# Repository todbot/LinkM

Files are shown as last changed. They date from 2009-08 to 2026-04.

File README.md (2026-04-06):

# LinkM -- USB to I2C adapter for BlinkM Smart LEDs

2010-2026 Tod E. Kurt, ThingM

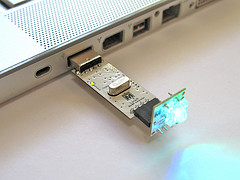
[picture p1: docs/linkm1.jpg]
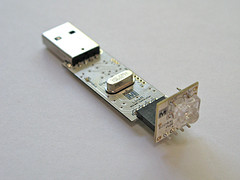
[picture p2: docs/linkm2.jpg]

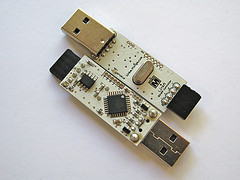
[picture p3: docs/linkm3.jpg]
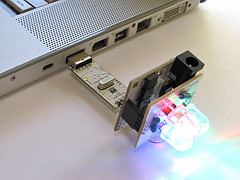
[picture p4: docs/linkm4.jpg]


LinkM datasheet: https://github.com/todbot/LinkM/raw/master/docs/LinkM_datasheet.pdf

Hosted on Github at https://github.com/todbot/LinkM/

## BlinkMSequencer

Create BlinkM light scripts using a drum machine-style metaphor and requires no
programming or hardware experience.

Modern BlinkMSequencer at https://github.com/todbot/BlinkMSequencer

Available for MacOS / Windows / Linux.

## linkm-tool

Commandline tool for controlling LinkM and BlinkMs.

Pre-compiled versions available in the [Releases section](https://github.com/todbot/LinkM/releases).

## Repo contents

This project contains the following directories:

- c_host          -- C library for talking to LinkM
  - linkm-tool       -- Command-line tool for exercising C library

- java_host       -- Java library for talking to LinkM
  - linkm.sh         -- Command-line tool for exercising Java library

- processing_apps -- Several applications using Java library and Processing
  - BlinkMSequencer2 -- Multi-channel light sequencer
  - BlinkMScriptTool -- Helps write text light scripts
  - TwitterBlinkM    -- Turns BlinkMs colors from twitter stream mentions
  - OSCLinkM         -- OSC gateway for LinkM
  - LinkMLibTest     -- Simple tests of LinkM Processing/Java library

- tools           -- Misc tools
  - linkm_load       -- mass bootloading tool
  - linux_usb_setup  -- fixes USB permissions on Ubuntu & other udev Linux

- schematic       -- LinkM device schematics in Eagle format

- firmware        -- LinkM device firmware code

- bootloadHID     -- LinkM device bootloader firmware and commandline tool
  - firmware         -- firmware for bootloader
  - commandline      -- commandline host-side tool to upload new firmware

## Building linkm-tool

The build process for linkm-tool is expected to be done entirely from the
command-line using standard free Unix-like tools such as "make" and "gcc".

On unix-like environments, the build process is just:

```sh
cd LinkM/c_host
make
```

Dependencies:
- The C library in "c_host" depends on library in "bootloadHID/commandline"
- `c_host/linkm-tool` requires **hidapi** (replaces the older libusb dependency)

On Mac OS X you will need the following free tools:
- XCode - http://developer.apple.com/technologies/xcode.html
- hidapi - `brew install hidapi`

On Windows (MinGW/MSYS2) you will need:
- MinGW/MSYS2 - https://www.msys2.org/
- The Windows build uses the native Win32 HID API; no extra library needed.

On Ubuntu / Debian Linux you will need:
- build-essential - `sudo apt-get install build-essential`
- hidapi - `sudo apt-get install libhidapi-dev`

On Fedora / RHEL Linux:
- `sudo dnf install hidapi-devel`

On Arch Linux:
- `sudo pacman -S hidapi`

On Linux, non-root users also need permission to access the device.
Add udev rules and reload:

```sh
cat << 'EOF' | sudo tee /etc/udev/rules.d/99-linkm.rules
SUBSYSTEM=="hidraw", ATTRS{idVendor}=="20a0", ATTRS{idProduct}=="4110", MODE="0666"
SUBSYSTEM=="usb",    ATTR{idVendor}=="20a0",  ATTR{idProduct}=="4110",  MODE="0666"
EOF
sudo udevadm control --reload-rules && sudo udevadm trigger
```

### Building the LinkM firmware

In general you should have everything you have for the host code above, and:

On Mac OS X:
- AVR CrossPack - http://www.obdev.at/products/crosspack/

On Windows:
- WinAVR - http://winavr.sourceforge.net/

On Ubuntu Linux:
- "sudo apt-get install avrdude avr-libc avr-gcc avr-binutils"

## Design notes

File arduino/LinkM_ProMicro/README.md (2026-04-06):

# LinkM Emulator for Arduino Pro Micro (ATmega32U4)

Make an Arduino act like a ThingM LinkM!

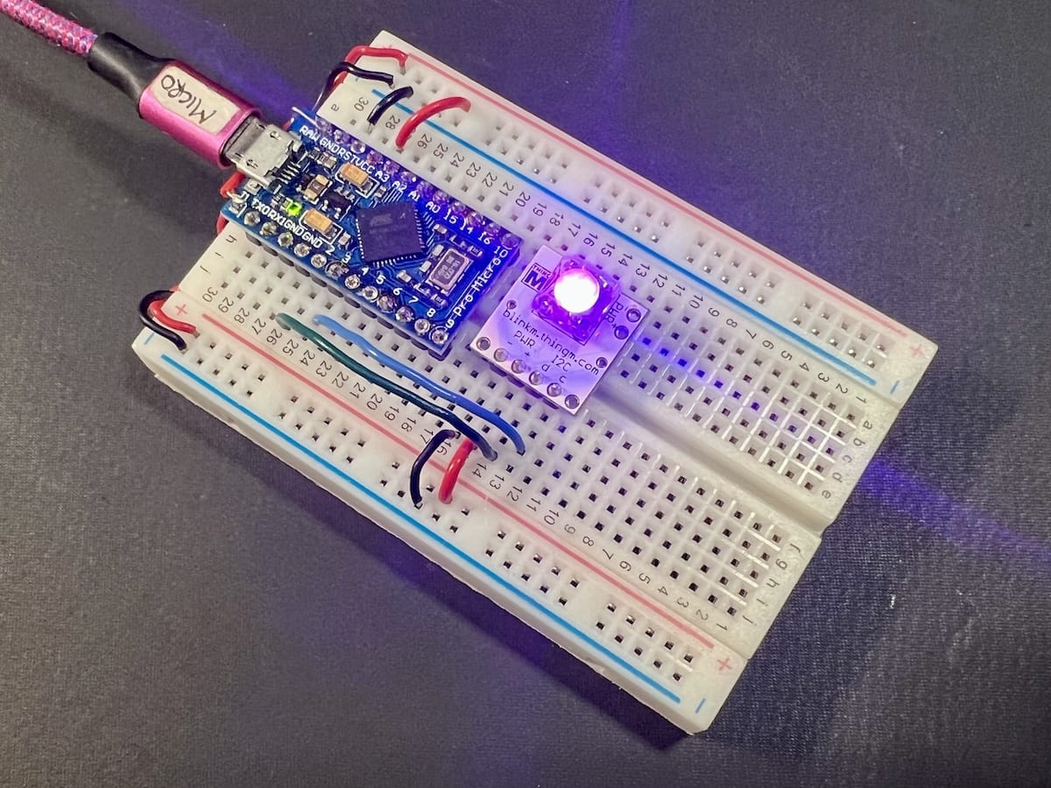
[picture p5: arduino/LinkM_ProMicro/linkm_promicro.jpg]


Firmware that turns a SparkFun Pro Micro (ATmega32U4) into a drop-in replacement
for a ThingM LinkM USB HID to I2C adapter.  The emulator implements the same USB
HID identity and feature-report protocol as the original hardware.

The host-side tool (`c_host/linkm-tool`) must be built from this repository — it
uses hidapi rather than libusb, which allows the Pro Micro's CDC serial interface
to remain active alongside the HID interface.

---

## What this does

The original LinkM is an ATmega88P device using V-USB (software USB) to present a
USB HID interface to the host.  The host sends commands via **HID feature reports**
(SET_REPORT / GET_REPORT control transfers, Report ID 1, 8 bytes) which the firmware
translates into I2C transactions.

This sketch ports that firmware to the ATmega32U4's native USB hardware, using
Arduino's `PluggableUSB` API to implement the same HID descriptor and feature-report
protocol.  From the host's perspective the device is identical:

| Property | Value |
|---|---|
| USB Vendor ID  | `0x20A0` |
| USB Product ID | `0x4110` |
| Manufacturer | `ThingM` |
| Product | `LinkM` |
| HID interface  | Vendor feature report, Report ID 1, 8 bytes |

---

## File overview

| File | Purpose |
|---|---|
| `LinkM_ProMicro.ino`  | `setup()` / `loop()` — 10 lines |
| `LinkMHID.h` | `PluggableUSBModule` subclass declaration |
| `LinkMHID.cpp` | USB descriptors, feature-report handling, all 13 commands, I2C via Wire, EEPROM, play-ticker |
| `linkm_protocol.h` | Command/error constants (mirrors `c_host/linkm-lib.h`) |

---

## Hardware

**Board:** SparkFun Pro Micro — **5V / 16 MHz** variant (ATmega32U4)

> **Important:** The SparkFun Pro Micro board package defaults to the
> **3.3 V / 8 MHz** processor option.  You must select **ATmega32U4 (5V, 16 MHz)**
> before compiling.  At 8 MHz the USB timing is out of spec for full-speed USB
> and the device will fail to enumerate reliably.
>
> In the Arduino IDE: **Tools → Processor → ATmega32U4 (5V, 16 MHz)**
>
> With arduino-cli the FQBN option `:cpu=16MHzatmega32U4` (shown in all compile
> commands below) selects this mode.

**I2C wiring:**

| Pro Micro pin | Signal | Notes |
|---|---|---|
| 2 (SDA) | SDA | 4.7 kΩ pull-up to VCC |
| 3 (SCL) | SCL | 4.7 kΩ pull-up to VCC |
| GND | GND | Common ground with I2C devices |

The I2C bus runs at 100 kHz.  Pro Micro is the bus master; all BlinkMs and other
I2C peripherals are slaves.

---

## Prerequisites

### 1. arduino-cli

```sh
brew install arduino-cli      # macOS
# or download from https://arduino.cc/en/software#arduino-cli
```

Verify:

```sh
arduino-cli version
```

### 2. SparkFun AVR board package

```sh
arduino-cli config init
arduino-cli config add board_manager.additional_urls \
    https://raw.githubusercontent.com/sparkfun/Arduino_Boards/master/IDE_Board_Manager/package_sparkfun_index.json
arduino-cli core update-index
arduino-cli core install SparkFun:avr
```

Verify the Pro Micro board is visible:

```sh
arduino-cli board listall | grep promicro
# SparkFun Pro Micro    SparkFun:avr:promicro
```

### 3. No extra libraries required

All libraries used (`Wire`, `EEPROM`, `PluggableUSB`) are part of the Arduino AVR
core and ship with `SparkFun:avr`.

---

## Compile

The Pro Micro defaults to SparkFun's VID/PID (`0x1B4F / 0x9206`).  Pass the
LinkM identity flags on the command line:

```sh
cd LinkM/arduino/LinkM_ProMicro

arduino-cli compile \
    --fqbn SparkFun:avr:promicro:cpu=16MHzatmega32U4 \
    --build-property "build.extra_flags=-DUSB_VID=0x20A0 -DUSB_PID=0x4110 -DUSB_MANUFACTURER=\"ThingM\" -DUSB_PRODUCT=\"LinkM\"" \
    --clean \
    .
```

### Alternative: platform.local.txt

To avoid repeating the flags on every compile, create a `platform.local.txt`
file that injects them automatically:

```sh
PLATFORM_DIR=$(arduino-cli config dump --format json | \
    python3 -c "import sys,json; d=json.load(sys.stdin); \
    print(d['directories']['data'])")/packages/SparkFun/hardware/avr/1.1.13

cat > "$PLATFORM_DIR/platform.local.txt" << 'EOF'
build.extra_flags=-DUSB_VID=0x20A0 -DUSB_PID=0x4110 -DUSB_MANUFACTURER="ThingM" -DUSB_PRODUCT="LinkM"
EOF
```

With that file in place the shorter form works:

```sh
arduino-cli compile \
    --fqbn SparkFun:avr:promicro:cpu=16MHzatmega32U4 \
    --clean \
    .
```

> `platform.local.txt` is loaded after `platform.txt` and survives IDE/CLI
> restarts, but must be recreated if the SparkFun package is updated to a new
> version directory.

---

## Upload

The board appears as a CDC serial port while running.  Find the port and upload:

```sh
arduino-cli board list
# Port                    Protocol  Type              Board Name
# /dev/cu.usbmodem14101   serial    Serial Port (USB) SparkFun Pro Micro

arduino-cli upload \
    --fqbn SparkFun:avr:promicro:cpu=16MHzatmega32U4 \
    --port /dev/cu.usbmodem14101 \
    .
```

If the board is unresponsive (no serial port visible), force it into the
Caterina bootloader manually:

1. **Briefly connect RST to GND twice in quick succession** (the Pro Micro has
   no reset button — use a jumper wire or tweezers on the RST and GND pins).
   The RX LED will begin pulsing, indicating the bootloader is active.
2. Within 8 seconds, find the bootloader port and upload:

```sh
arduino-cli board list
# find the new port, then:
arduino-cli upload \
    --fqbn SparkFun:avr:promicro:cpu=16MHzatmega32U4 \
    --port /dev/cu.usbmodem14101 \
    .
```

> The bootloader port is a different path from any previous port.  Run
> `arduino-cli board list` immediately after the double-tap to see it.
>
> If the upload still fails, try again — the timing window is ~8 seconds.

After a successful upload the board re-enumerates with VID=0x20A0 / PID=0x4110,
presenting both a CDC serial port and the HID interface.

---

## Verify enumeration

**macOS:**

```sh
system_profiler SPUSBDataType | grep -A 8 "LinkM"
```

Expected output:

```
LinkM:
  Product ID: 0x4110
  Vendor ID: 0x20a0
  Manufacturer: ThingM
  ...
```

**Linux:**

```sh
lsusb -d 20a0:4110
# Bus 001 Device 012: ID 20a0:4110 ThingM LinkM
```

---

## Test with linkm-tool

Build the host tool from this repository:

```sh
cd LinkM/c_host
make
```

Run tests (no I2C hardware needed for the first two):

```sh
# Firmware version — exercises a full SET_REPORT + GET_REPORT round-trip
./linkm-tool --linkmversion
# Expected: LinkM version 0x13 0x36

# Status LED toggle
./linkm-tool --statled 1
./linkm-tool --statled 0

# I2C scan (requires devices on SDA/SCL with pull-ups)
./linkm-tool --i2cscan

# BlinkM at address 9: stop, set colour to red, play script 0
./linkm-tool -a 9 --stop
./linkm-tool -a 9 --color 255,0,0
./linkm-tool -a 9 --play 0

# EEPROM round-trip
./linkm-tool --linkmeesave
./linkm-tool --linkmeeload
./linkm-tool --linkmversion   # confirm still responsive
```

---

## Implementation notes

### Commands supported

All 13 original LinkM commands are implemented:

| Cmd | Value | Notes |
|-----|---|---|
| I2CTRANS | 1 | Write + optional repeated-START read |
| I2CWRITE | 2 | Write, optionally hold bus open |
| I2CREAD | 3 | Read only |
| I2CSCAN | 4 | Probe each address; returns list of ACK'd devices |
| I2CCONN | 5 | No-op (no bus-isolation chip on Pro Micro) |
| I2CINIT | 6 | `Wire.end()` / `Wire.begin()` / `setClock(100000)` |
| VERSIONGET | 100 | Returns `0x13` / `0x36` (matches original firmware) |
| STATLEDSET | 101 | TX LED (pin 30, `LED_BUILTIN_TX`) — persistent state |
| STATLEDGET | 102 | |
| PLAYSET | 103 | Sets autonomous BlinkM play-ticker params |
| PLAYGET | 104 | |
| EESAVE | 105 | `EEPROM.put()` at address 0 |
| EELOAD | 106 | `EEPROM.get()` at address 0 |
| GOBOOTLOAD | 107 | Writes Caterina magic key `0x7777` → watchdog reset |

### PLAYSET buffer limit

The 8-byte feature report can carry at most 4 param bytes for PLAYSET (indices
4–7 of `rxBuf`): `playing`, `script_id`, `script_tick`, `script_len`.  The
original firmware had the same effective limit.  `start_pos`, `fadespeed`, and
`dir` are preserved from the last EELOAD or retain their defaults.

### Play-ticker timing

The original firmware fired at `12 MHz / 65536 / 6 ≈ 30.5 Hz` giving ~32.8 ms
per tick.  The emulator uses `millis()` with 33 ms per tick unit to match this
rate.

### I2C repeated START

`Wire.endTransmission(false)` (sendStop=false) is used when a read follows a
write in the same I2CTRANS command, issuing a repeated START rather than a
STOP+START.  This is required by BlinkM and many other I2C peripherals.

### Linux udev rule

On Linux, add udev rules so non-root users can access the device.  Two rules are
needed: one for the hidraw node (used by hidapi) and one for the USB device:

```sh
cat << 'EOF' | sudo tee /etc/udev/rules.d/99-linkm.rules
SUBSYSTEM=="hidraw", ATTRS{idVendor}=="20a0", ATTRS{idProduct}=="4110", MODE="0666"
SUBSYSTEM=="usb",    ATTR{idVendor}=="20a0",  ATTR{idProduct}=="4110",  MODE="0666"
EOF
sudo udevadm control --reload-rules && sudo udevadm trigger
```

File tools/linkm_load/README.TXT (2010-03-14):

LinkMv1 Testing Script            -- 20100314, ThingM, Tod E. Kurt
======================

Note:
-----
- This script assumes a Windows computer is the USB host.  
- A Linux computer may also be used (with optional file supplied)
- The "linkm_load.bat" batch file runs in a loop to speed testing

Script:
-------
1. Connect shorting jumper across pins 'o' and '-' on "isp" header

2. Plug LinkM board into USB host machine
   
3. Observe LED1 "status" should light and stay lit

4. Observe LinkM unit properly negotiates with USB host
   - LinkM unit should appear in host's USB device list as HID device with:
     - USB VendorID = 0x20A0
     - USB DeviceID = 0x4110 
     - USB VendorName = "ThingM"
     - USB DeviceName = "LinkMBoot"

5. Run Windows batch file "linkm_load.bat"
     - Observe the screen print out the message:
         Page size   = 64 (0x40)
         Device size = 8192 (0x2000); 6144 bytes remaining
         Uploading 4224 (0x1080) bytes starting at 0 (0x0)
         0x01000 ... 0x01080
         Flashing done.
         Switching from LinkMBoot to LinkM...
      - It should NOT say "Error opening LinkM"

6. Observe LED2 "enable" should light and stay lit

7. Observe LinkM unit switches to "LinkM" mode and reconnects with USB host as:
     - USB VendorID = 0x20A0
     - USB DeviceID = 0x4110 
     - USB VendorName = "ThingM"
     - USB DeviceName = "LinkM"

8. If any of the above observations fail, mark unit FAIL, other mark PASS

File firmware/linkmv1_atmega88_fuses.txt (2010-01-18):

Fuse settings for "linkmv1_atmega88.hex"  -- 20100115, Tod E. Kurt, ThingM.com
----------------------------------------
FUSE_L = 0xFF
FUSE_H = 0xDD
FUSE_E = 0x00
FUSE_LOCK = 0x0F

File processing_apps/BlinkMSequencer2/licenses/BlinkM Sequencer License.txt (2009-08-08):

Copyright (c) 2007-2008, ThingM Corporation
* All rights reserved.
*
* Redistribution and use in source and binary forms, with or without
* modification, are permitted provided that the following conditions are met:
*     * Redistributions of source code must retain the above copyright
*       notice, this list of conditions and the following disclaimer.
*     * Redistributions in binary form must reproduce the above copyright
*       notice, this list of conditions and the following disclaimer in the
*       documentation and/or other materials provided with the distribution.
*     * Neither the name of the ThingM Corporation nor the
*       names of its contributors may be used to endorse or promote products
*       derived from this software without specific prior written permission.
*
* THIS SOFTWARE IS PROVIDED BY THINGM CORPORATION ``AS IS'' AND ANY
* EXPRESS OR IMPLIED WARRANTIES, INCLUDING, BUT NOT LIMITED TO, THE IMPLIED
* WARRANTIES OF MERCHANTABILITY AND FITNESS FOR A PARTICULAR PURPOSE ARE
* DISCLAIMED. IN NO EVENT SHALL THINGM CORPORATION BE LIABLE FOR ANY
* DIRECT, INDIRECT, INCIDENTAL, SPECIAL, EXEMPLARY, OR CONSEQUENTIAL DAMAGES
* (INCLUDING, BUT NOT LIMITED TO, PROCUREMENT OF SUBSTITUTE GOODS OR SERVICES;
* LOSS OF USE, DATA, OR PROFITS; OR BUSINESS INTERRUPTION) HOWEVER CAUSED AND
* ON ANY THEORY OF LIABILITY, WHETHER IN CONTRACT, STRICT LIABILITY, OR TORT
* (INCLUDING NEGLIGENCE OR OTHERWISE) ARISING IN ANY WAY OUT OF THE USE OF THIS
* SOFTWARE, EVEN IF ADVISED OF THE POSSIBILITY OF SUCH DAMAGE.

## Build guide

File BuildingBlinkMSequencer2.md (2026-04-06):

### BlinkMSequencer2 (old)

The below BlinkMSequencer2 will likely not work, as things have evolved 
much in 15 years. 

A. Bundle for Mac OS X
  1. Open BlinkMSequencer2 in Processing
  2. Choose File -> Export Application, choose "Mac OS X"
  3. In Finder, open linkm/processing_apps/BlinkMSequencer2/application.macosx
  4. Add Icon:
  4a.  Right-click "BlinkMSequencer2.app", choose "Get Info"
  4b.  Open "linkm/tools/bundle_bits/thingm_log-10.png" in Preview.
  4c.  Select All, copy, then select icon in Info inspector, and paste
  5. Right-click "BlinkMSequencer2.app", choose "Compress ..."
  6. Rename resulting zip as "BlinkMSequencer2_macosx.zip"
  7. Publish release

B. Bundle for Windows:
  1. Open BlinkMSequencer2 in Processing
  2. Choose File -> Export Application, choose your "Windows"
  3. Bundle with Java with these 5 command-line commands:
  ```
     cd linkm/processing_apps/BlinkMSequencer2/application.windows
     unzip ../../../tools/bundle_bits/java_from_arduino_0018_win.zip
     cd ..
     mv application.windows BlinkMSequencer2_windows
     zip -r BlinkMSequencer2_windows.zip BlinkMSequencer2_windows
  ```
  4. Publish release

C. Bundle for Linux:
  1. Open BlinkMSequencer2 in Processing
  2. Choose File -> Export Application, choose "Linux"
  3. Bundle with the following 3 command-line commands:
  ```
     cd linkm/processing_apps/BlinkMSequencer2
     mv application.linux BlinkMSequencer2_linux
     tar cvzf BlinkMSequencer2_linux.tar.gz BlinkMSequencer2_linux
  ```
  4. Publish release

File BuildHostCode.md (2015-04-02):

Introduction
------------
How to build the LinkM library and example code.

Details
-------
The build process for all LinkM software except the Processing apps is expected to be done entirely from the command-line using standard free Unix-like tools such as "make" and "gcc".

There is a build_all_host.sh script that will build the host-side code on all OS platforms.

Host code dependencies:
-----------------------
- The Java library in "java_host" depends on the C library in "c_host"
- The C library in "c_host" depends on library in "bootloadHID/commandline"

On Mac OS X you will need the following free tools:

- XCode - http://developer.apple.com/technologies/xcode.html
- libusb - "sudo port install libusb-legacy libusb" (port is available from http://macports.org/ )

On Windows you will need the following free tools:

- MinGW - http://www.mingw.org/
- MSYS - http://www.mingw.org/wiki/MSYS
- zip - http://stahlworks.com/dev/index.php?tool=zipunzip
- Java JDK - http://java.sun.com/javase/downloads/widget/jdk6.jsp

On Ubuntu Linux you will need the following free tools:

- build-essential - 'sudo apt-get install build-essential'
- libusb - 'sudo apt-get install libusb libusb-dev'
- Sun JDK - 'sudo add-apt-repository "deb http://archive.canonical.com/ lucid partner" && sudo apt-get update && sudo apt-get install sun-java6-jdk'

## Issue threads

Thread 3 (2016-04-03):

LinkM - missing .dylib for OSX

lobsteroh, 2016-04-03:
i am compiling the LinkM on Mac OSX with

    $ bash build_all_host.sh

and it creates files

    LinkM.dll	export.txt	libLinkM.jnilib	libLinkM.so	linkm.jar

there is no .dylib file and the .so does not appear to be a functional object file ...

    $ otool -hv libLinkM.so

produces

    libLinkM.so: is not an object file

when i include the jar and .so in my java project I get ...

`Exception in thread "main" java.lang.UnsatisfiedLinkError: thingm.linkm.LinkMStarter.command(I[B[B)V
	at thingm.linkm.LinkMStarter.command(Native Method)
	at thingm.linkm.LinkMStarter.getVersion(LinkMStarter.java:59)
	at thingm.linkm.LinkMStarter.main(LinkMStarter.java:67)
`

any suggestions?

todbot, 2016-04-06:
Java on Mac OS X uses a .jnilib file, not .dylib.  That file is in there.  But I think because of changes in Java and/or OS X, the previous build wasn't working.  I've rebuilt it and released it here:
https://github.com/todbot/LinkM/releases/tag/20160406

lobsteroh, 2016-04-06:
hi tod, thanks a stack. i can confirm that this one is working fine. trying to dig through the BlinkMSequencer2 code for the nuggets of value was a bear, if you are interested, here is a class with a barebones communication to I2C device via LinkM. feel free to use, adapt, or ignore.

[BlinkMController.pdf](https://github.com/todbot/LinkM/files/207069/BlinkMController.pdf)

Closed 2016-04-06.

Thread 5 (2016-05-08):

troubling timing issue?

lobsteroh, 2016-05-08:
oh no, i am running into communication errors with any repeated i2c reads. I get the same with 4 different kinds of i2c chips, and even the BlinkMs. the following example code

			int addr = 9;
			int counter = 0;
			while (counter<100) {
				System.out.println(counter + ": ");
				linkm.getVersion(addr);
				//Thread.sleep(500);
				counter++;
			}

runs for a few times then throws IOException

    Error sending message: usb_control_msg(DeviceRequestTO): the device is not responding
    error reading data: Communication error with device
    java.io.IOException: Communication error with device
	at thingm.linkm.LinkM.command(Native Method)
	at thingm.linkm.LinkM.commandi2c(LinkM.java:502)

if I make the Thread sleep, successful completions go up. A sleep of 500ms is needed to have this task start to run somewhat reliably. any idea on where this issue creeps in and how to fix it? - MacOSX 10.11.4, LinkM, BlinkM.

lobsteroh, 2016-05-08:
update ... reporting on various suggestions on how to fix ...

add 100nF capacitor between VCC and ground - does not change failure

lobsteroh, 2016-05-08:
is libusb-legacy the issue, can i switch to libusb?

todbot, 2016-05-11:
Hi, libusb-0.1 (which is what libusb-legacy is pretending to be) is what's needed for the current LinkM library.  libusb-1.0 has an entirely different API.

I'm not sure what's requiring you to wait ~500msec. I've been looking into it and it does seem like a driver issue, but I've not found anything telling yet.

lobsteroh, 2016-05-11:
hi tod, thanks a stack, in playing with this, the faults look really random. even if i issue the read commands at full speed i sometimes get 15 reads until it fails. it almost looks like something not being ready to communicate between linkm and PC, rather than on the serial output end of the linkm. can you confirm that your setup is running into the same issue, or is my system screwing things up. let me know if i can be of help in testing, troubleshooting or developing. be well,

lobsteroh, 2016-05-12:
ok, looks like a usb3 vs usb2 issue. When i plug the LinkM into a usb2 hub, and that into the usb3 port on my mac, then the linkm starts to play a lot nicer.

stonehippo, 2024-07-04:
I know this ancient thread, but just dropping in to add a data that this seems to be an issue with some USB3+ ports. When I had the linkm connected to the USB-C port on my Macbook Air (USB4), it reported I2C comms issues. Plugging it into a USB2 hub and things work great.

Can probably close this one, if you're so inclined, @todbot.

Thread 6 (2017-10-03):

compile

dunk8888, 2017-10-03:
Hi,if i wanted to compile this with processing witch version would i use,ime getting errore with the current version,I know there is one compiled allready,i want to play around with this a bit.thanks

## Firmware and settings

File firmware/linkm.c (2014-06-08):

/*
 * LinkM firmware - USB HID to I2C adapter for BlinkM
 *
 * Command format:  (from host perspective)
 *
 * pos description
 *  0    <startbyte>      ==  0xDA
 *  1    <linkmcmdbyte>   ==  0x01 = i2c transaction, 0x02 = i2c bus scan, etc. 
 *  2    <num_bytes_send> ==  starting at byte 4
 *  3    <num_bytes_recv> ==  may be zero if nothing to send back
 *  4..N <cmdargs>        == command 
 *
 * For most common command, i2c transaction (0x01):
 * pos  description
 *  0   0xDA
 *  1   0x01
 *  2   <num_bytes_to_send>
 *  3   <num_bytes_to_receive>
 *  4   <i2c_addr>   ==  0x00-0x7f
 *  5   <send_byte_0>
 *  6   <send_byte_1>
 *  7   ...
 *
 * Command byte values
 *  0x00 = no command, do not use
 *  0x01 = i2c transact: read + opt. write (N arguments)
 *  0x02 = i2c read                        (N arguments)
 *  0x03 = i2c write                       (N arguments)
 *  0x04 = i2c bus scan                    (2 arguments, start addr, end addr)
 *  0x05 = i2c bus connect/disconnect      (1 argument, connect/disconect)
 *  0x06 = i2c init                        (0 arguments)
 *
 *  0x100 = set status LED                  (1 argument)
 *  0x101 = get status LED
 * 
 * Response / Output buffer format:
 * pos description
 *  0   transaction counter (8-bit, wraps around)
 *  1   response code (0 = okay, other = error)
 *  2   <resp_byte_0>
 *  3   <resp_byte_1>
 *  4   ...
 *
 * 2009, Tod E. Kurt, ThingM, http://thingm.com/
 *
 */

#include <avr/io.h>
#include <avr/wdt.h>        // watchdog
#include <avr/eeprom.h>     //
#include <avr/interrupt.h>  // for sei() 
#include <util/delay.h>     // for _delay_ms() 
#include <string.h>

#include <avr/eeprom.h>
#include <avr/pgmspace.h>   // required by usbdrv.h 
#include "usbdrv.h"
#include "oddebug.h"        // This is also an example for using debug macros 

#include "i2cmaster.h"
#include "uart.h"

#include "linkm-lib.h"

// uncomment to enable debugging to serial port
#define DEBUG   1

#define ENABLE_PLAYTICKER 1

// these aren't used anywhere, just here to note them
#define PIN_LED_STATUS         PORTB4
#define PIN_I2C_ENABLE         PORTB5

#define PIN_I2C_SDA            PORTC4
#define PIN_I2C_SCL            PORTC5

#define PIN_USB_DPLUS          PORTD2
#define PIN_USB_DMINUS         PORTD3

#define LINKM_VERSION_MAJOR    0x13
#define LINKM_VERSION_MINOR    0x36   // not quite leet yet

#if DEUBG > 0
#define printdebug(str)
#define putchdebug(c)
#else
#define printdebug(str) fputs(str,stdout)
#define putchdebug(c)   uart_putchar(c,stdout)
#endif

/* ------------------------------------------------------------------------- */
/* ----------------------------- USB interface ----------------------------- */
/* ------------------------------------------------------------------------- */

#define REPORT1_COUNT 8
#define REPORT2_COUNT 131

PROGMEM char usbHidReportDescriptor[33] = {
    0x06, 0x00, 0xff,              // USAGE_PAGE (Generic Desktop)
    0x09, 0x01,                    // USAGE (Vendor Usage 1)
    0xa1, 0x01,                    // COLLECTION (Application)
    0x15, 0x00,                    //   LOGICAL_MINIMUM (0)
    0x26, 0xff, 0x00,              //   LOGICAL_MAXIMUM (255)
    0x75, 0x08,                    //   REPORT_SIZE (8)

    0x85, 0x01,                    //   REPORT_ID (1)
    0x95, REPORT1_COUNT,           //   REPORT_COUNT (was 6)
    0x09, 0x00,                    //   USAGE (Undefined)
    0xb2, 0x02, 0x01,              //   FEATURE (Data,Var,Abs,Buf)

    0xc0                           // END_COLLECTION
};

/* Since we define only one feature report, we don't use report-IDs (which
 * would be the first byte of the report). The entire report consists of
 * REPORT_COUNT opaque data bytes.
 */

/* The following variables store the status of the current data transfer */
static uchar    currentAddress;
static uchar    bytesRemaining;

//static int numWrites;  // FIXME: what was this for?

static uint8_t inmsgbuf[REPORT1_COUNT];
static uint8_t outmsgbuf[REPORT1_COUNT];
static uint8_t reportId;  // which report Id we're currently working on

static volatile uint16_t tick;         // tick tock clock
static volatile uint16_t timertick;         // tick tock clock

static uint8_t goReset = 0;   // set to 1 to reset 

#if DEBUG > 0
#warning "DEBUG is enabled!"
#warning "DEBUG is enabled!"
#warning "DEBUG is enabled!"
// setup serial routines to become stdio
extern int uart_putchar(char c, FILE *stream);
extern int uart_getchar(FILE *stream);
FILE uart_str = FDEV_SETUP_STREAM(uart_putchar, uart_getchar, _FDEV_SETUP_RW);
#endif

typedef struct _params_t {
    uint8_t  playing;      // turn on or off playing
    uint8_t  script_id;    // script id to play
    uint8_t  script_tick;  // number of ticks between script lines
    uint8_t  script_len;   // number of script lines in script
    uint8_t  start_pos;    // start position in the script  FIXME: not impl yet
    uint8_t  fadespeed;    //
    uint8_t  dir;          // play direction FIXME: not impl yet
} params_t;

params_t params;           // local RAM copy of playTicker params
uint16_t script_pos;       // position for playTicker

// magic value read on reset: 0x55 = run bootloader , other = boot normally
#define GOBOOTLOAD_MAGICVAL 0x55
uint8_t bootmode EEMEM = 0; 
params_t ee_params EEMEM = {
    0,   // playing
    0,   // script_id
    0,   // script_tick
    0,   // script_len
    0,   // start_pos
    100, // fadespeed
    0,   // dir
};
//params_t ee_params EEMEM = {
//    1,5,5,2, 0,100,0
//};

int blinkmStop(uint8_t addr );
int blinkmSetRGB(uint8_t addr, uint8_t r, uint8_t g, uint8_t b );
int blinkmSetFadespeed(uint8_t addr, uint8_t fadespeed);
int blinkmPlayScript(uint8_t addr, uint8_t id, uint8_t reps, uint8_t pos);

//void(* softReset) (void) = 0;  //declare reset function @ address 0

static void (*nullVector)(void) __attribute__((__noreturn__));

static void resetChip()
{
    cli();
    USB_INTR_ENABLE = 0;
    USB_INTR_CFG = 0;       /* also reset config bits */
    nullVector();
}

// ------------------------------------------------------------------------- 
void statusLedToggle(void)
{
    PORTB ^= (1<< PIN_LED_STATUS);  // toggles LED
}
void statusLedSet(int v)
{
    if( v ) PORTB  |=  (1<<PIN_LED_STATUS);
    else    PORTB  &=~ (1<<PIN_LED_STATUS);
}
uint8_t statusLedGet(void)
{
    return (PINB & (1<<PIN_LED_STATUS)) ? 1 : 0;
}

void i2cEnable(int v) {
    if( v ) PORTB  |=  (1<<PIN_I2C_ENABLE);
    else    PORTB  &=~ (1<<PIN_I2C_ENABLE);
}

// 
// Called from usbFunctionWrite() when we've received the entire USB message
// 
void handleMessage(void)
{
    statusLedSet(1);
    uint8_t ledval = 0;

    //outmsgbuf[0]++;                   // say we've handled a msg
    outmsgbuf[0] = reportId;          // reportID   FIXME: Hack
    outmsgbuf[1] = LINKM_ERR_NONE;    // be optimistic
    // outmsgbuf[2] starts the actual received data

    uint8_t* inmbufp = inmsgbuf+1;  // was +1 because had forgot to send repotid

    if( inmbufp[0] != START_BYTE  ) {   // byte 0: start marker
        outmsgbuf[1] = LINKM_ERR_BADSTART;
        goto doneHandleMessage; //return;
    }
    
    uint8_t cmd      = inmbufp[1];     // byte 1: command
    uint8_t num_sent = inmbufp[2];     // byte 2: number of bytes sent
    uint8_t num_recv = inmbufp[3];     // byte 3: number of bytes to return back

#if DEBUG > 0
    printf("\nc:%d s:%d r:%d ",cmd,num_sent,num_recv); // FIXME: fat
#endif

    // i2c transaction
    // params:
    //   mpbufp[4] == i2c addr
    //   mpbufp[5..5+numsend] == data to write
    // returns:
    //   outmsgbuf[0] == transaction counter 
    //   outmsgbuf[1] == response code
    //   outmsgbuf[2] == i2c response byte 0  (if any)
    //   outmsgbuf[3] == i2c response byte 1  (if any)
    // ...
    // FIXME: because "num_sent" and "num_recv" are outside this command
    //        it's confusing
    if( cmd == LINKM_CMD_I2CTRANS ) {
        uint8_t addr      = inmbufp[4];  // byte 4: i2c addr or command

        putchdebug('A');
        if( addr >= 0x80 ) {   // invalid valid I2C address
            outmsgbuf[1] = LINKM_ERR_BADARGS;
            goto doneHandleMessage; //return;
        }

        putchdebug('B');
        if( i2c_start( (addr<<1) | I2C_WRITE ) == 1) {  // start i2c trans
            printdebug("!");
            outmsgbuf[1] = LINKM_ERR_I2C;
            i2c_stop();
            goto doneHandleMessage; //return;
        }
        putchdebug('C');
        // start succeeded, so send data
        for( uint8_t i=0; i<num_sent-1; i++) {
            i2c_write( inmbufp[5+i] );   // byte 5-N: i2c command to send
        }

        putchdebug('D');
        if( num_recv != 0 ) {
            if( i2c_rep_start( (addr<<1) | I2C_READ ) == 1 ) { // start i2c
                outmsgbuf[1] = LINKM_ERR_I2CREAD;
            }
            else {
                for( uint8_t i=0; i<num_recv; i++) {
                    //uint8_t c = i2c_read( (i!=(num_recv-1)) );//read from i2c
                    int c = i2c_read( (i!=(num_recv-1)) ); // read from i2c
                    if( c == -1 ) {  // timeout, get outx
                        outmsgbuf[1] = LINKM_ERR_I2CREAD;
                        break;
                    }
                    outmsgbuf[2+i] = c;             // store in response buff
                }
            }
        }
        putchdebug('Z');
        i2c_stop();  // done!
    }
    // i2c write
    // params:
    //   mbufp[4]     == i2c addr
    //   mbufp[5]     == read after write boolean (1 == read, 0 = no read)
    // returns:
    //   outmsgbuf[0] == transaction counter 
    //   outmsgbuf[1] == response code
    // FIXME: this function doesn't work i think
    else if( cmd == LINKM_CMD_I2CWRITE ) {
        uint8_t addr      = inmbufp[4];  // byte 4: i2c addr or command
        uint8_t doread    = inmbufp[5];  // byte 5: do read or not after this

        if( addr >= 0x80 ) {   // invalid valid I2C address
            outmsgbuf[1] = LINKM_ERR_BADARGS;
            goto doneHandleMessage; //return;
        }

        if( i2c_start( (addr<<1) | I2C_WRITE ) == 1) {  // start i2c trans
            outmsgbuf[1] = LINKM_ERR_I2C;
            i2c_stop();
            goto doneHandleMessage; //return;
        }
        // start succeeded, so send data
        for( uint8_t i=0; i<num_sent-1; i++) {
            i2c_write( inmbufp[5+i] );   // byte 5-N: i2c command to send
        } 
        if( !doread ) {
            i2c_stop();   // done!
        }
    }
    // i2c read
    // params:
    //   mpbuf[4]     == i2c addr 
    // returns:
    //   outmsgbuf[0] == transaction counter 
    //   outmsgbuf[1] == response code
    //   outmsgbuf[2] == i2c response byte 0  (if any)
    //   outmsgbuf[3] == i2c response byte 1  (if any)
    // ...
    else if( cmd == LINKM_CMD_I2CREAD ) {
        uint8_t addr      = inmbufp[4];  // byte 4: i2c addr 

        if( num_recv == 0 ) {
            outmsgbuf[1] = LINKM_ERR_BADARGS;
            goto doneHandleMessage; //return;
        }
        statusLedSet(1);

        if( i2c_rep_start( (addr<<1) | I2C_READ ) == 1 ) { // start i2c
            outmsgbuf[1] = LINKM_ERR_I2CREAD;
        }
        else {
            for( uint8_t i=0; i<num_recv; i++) {
                uint8_t c = i2c_read( (i!=(num_recv-1)) ); // read from i2c
                outmsgbuf[2+i] = c;             // store in response buff
            }
        }
        statusLedSet(0);
        i2c_stop();
    }
    // i2c bus scan
    // params:
    //   mbufp[4]     == start addr
    //   mbufp[5]     == end addr
    // returns:
    //   outmsgbuf[0] == transaction counter
    //   outmsgbuf[1] == response code
    //   outmsgbuf[2] == number of devices found
    //   outmsgbuf[3] == addr of 1st device
    //   outmsgbuf[4] == addr of 2nd device
    // ...
    else if( cmd == LINKM_CMD_I2CSCAN ) {
        uint8_t addr_start = inmbufp[4];  // byte 4: start addr of scan
        uint8_t addr_end   = inmbufp[5];  // byte 5: end addr of scan
        if( addr_start >= 0x80 || addr_end >= 0x80 || addr_start > addr_end ) {
            outmsgbuf[1] = LINKM_ERR_BADARGS;
            goto doneHandleMessage; //return;
        }
        int numfound = 0;
        for( uint8_t a = 0; a < (addr_end-addr_start); a++ ) {
            if( i2c_start( ((addr_start+a)<<1)|I2C_WRITE)==0 ) { // dev found
                outmsgbuf[3+numfound] = addr_start+a;  // save the address 
                numfound++;
            }
            i2c_stop();
        }
        outmsgbuf[2] = numfound;
    }
    // i2c bus connect/disconnect
    // params:
    //   mpbuf[4]  == connect (1) or disconnect (0)
    // returns:
    //   outmsgbuf[0] == transaction counter
    //   outmsgbuf[1] == response code
    else if( cmd == LINKM_CMD_I2CCONN  ) {
        uint8_t conn = inmbufp[4];        // byte 4: connect/disconnect boolean
        i2cEnable( conn );
    }
    // i2c init
    // params:
    //   none
    // returns:
    //   outmsgbuf[0] == transaction counter
    //   outmsgbuf[1] == response code
    else if( cmd == LINKM_CMD_I2CINIT ) {  // FIXME: what's the real soln here?
        i2c_stop();
        _delay_ms(1);
        i2c_init();
    }
    // set status led state
    // params:
    //   mbufp[4]  == on (1) or off (0)
    // returns:
    //   outmsgbuf[0] == transaction counter
    //   outmsgbuf[1] == response code
    else if( cmd == LINKM_CMD_STATLEDSET ) {
        ledval = inmbufp[4];        // byte 4: on/off boolean
    }
    // get status led state
    // params:
    //   none
    // returns:
    //   outmsgbuf[0] == transaction counter
    //   outmsgbuf[1] == response code
    //   outmsgbuf[2] == state of status LED
    else if( cmd == LINKM_CMD_STATLEDGET ) {
        // no arguments, just a single return byte
        outmsgbuf[2] = statusLedGet();
    }
    // set play statemachine params
    // params:
    //   mbufp[4] == playing on/off
    //   mbufp[5] == script_id
    //   mbufp[6] == ticks between steps
    //   mbufp[7] == length of script   and so on
    // returns:
    //  none
    else if( cmd == LINKM_CMD_PLAYSET ) { 
        memcpy( &params, inmbufp+4, sizeof(params_t));
        script_pos = params.start_pos;
        if( params.fadespeed != 0 ) {
            blinkmSetFadespeed(0, params.fadespeed);            
        }
    }
    // get player statemachine params
    // params:
    //   none
    // returns:
    //   outmsgbuf[0] == transaction counter
    //   outmsgbuf[1] == response code
    //   outmsgbuf[2] == playing 
    //   outmsgbuf[3] == script_id
    //   outmsgbuf[4] == script_tick 
    //   outmsgbuf[5] == script_len  nad so on
    else if( cmd == LINKM_CMD_PLAYGET ) { 
        memcpy( outmsgbuf+2, &params, sizeof(params_t));
    }
    // trigger LinkM to save current params to EEPROM
    // params:
    //   none
    // returns:
    //   none
    else if( cmd == LINKM_CMD_EESAVE ) {
        statusLedToggle();
        eeprom_write_block( &params, &ee_params, sizeof(params_t) ); 
    }
    // trigger LinkM to load its saved EEPROM params into RAM
    // params:
    //   none
    // returns:
    //   none
    else if( cmd == LINKM_CMD_EELOAD ) {
        statusLedToggle();
        eeprom_read_block( &params, &ee_params, sizeof(params_t) );
    }
    // get linkm version
    // params:
    //   none
    // returns:
    //   outmsgbuf[0] == transaction counter
    //   outmsgbuf[1] == response code
    //   outmsgbuf[2] == major linkm version
    //   outmsgbuf[3] == minor linkm version
    else if( cmd == LINKM_CMD_VERSIONGET ) {
        outmsgbuf[2] = LINKM_VERSION_MAJOR;
        outmsgbuf[3] = LINKM_VERSION_MINOR;
    }
    // reset into bootloader
    else if( cmd == LINKM_CMD_GOBOOTLOAD ) { 
        statusLedToggle();
        eeprom_write_byte( &bootmode, GOBOOTLOAD_MAGICVAL );
        goReset = 1;
    }
    // cmd xxxx == 

 doneHandleMessage:
    statusLedSet(ledval);

}

/* usbFunctionWrite() is called when the host sends a chunk of data to the
 * device. For more information see the documentation in usbdrv/usbdrv.h.
 */
uchar   usbFunctionWrite(uchar *data, uchar len)
{
    if(bytesRemaining == 0)
        return 1;               // end of transfer 
    if(len > bytesRemaining)
        len = bytesRemaining;
    
    memcpy( inmsgbuf+currentAddress, data, len );
    currentAddress += len;
    bytesRemaining -= len;
    
    if( bytesRemaining == 0 )  {   // got it all
        handleMessage();
    }
    
    return bytesRemaining == 0; // return 1 if this was the last chunk 
}

/* usbFunctionRead() is called when the host requests a chunk of data from
 * the device. For more information see the docs in usbdrv/usbdrv.h.
 */
uchar   usbFunctionRead(uchar *data, uchar len)
{
    if(len > bytesRemaining)
        len = bytesRemaining;
    
    memcpy( data, outmsgbuf + currentAddress, len);
    //numWrites = 0;
    currentAddress += len;
    bytesRemaining -= len;
    return len;
}

// ------------------------------------------------------------------------- 
/**
 *
 */
usbMsgLen_t usbFunctionSetup(uchar data[8])
{
    usbRequest_t    *rq = (void *)data;
    // HID class request 
    if((rq->bmRequestType & USBRQ_TYPE_MASK) == USBRQ_TYPE_CLASS) {
        // wValue: ReportType (highbyte), ReportID (lowbyte) 
        uint8_t rid = rq->wValue.bytes[0];  // report Id
        if(rq->bRequest == USBRQ_HID_GET_REPORT) {  
            if( rid == 1 || rid == 2 ) { 
                reportId = rid;
                bytesRemaining = (rid==1) ? REPORT1_COUNT : REPORT2_COUNT;
                currentAddress = 0;
                return USB_NO_MSG;  // use usbFunctionRead() to obtain data 
            }
        }
        else if(rq->bRequest == USBRQ_HID_SET_REPORT) {
            if( rid == 1 || rid == 2 ) { 
                reportId = rid;
                bytesRemaining = (rid==1) ? REPORT1_COUNT : REPORT2_COUNT;
                currentAddress = 0;
                return USB_NO_MSG;  // use usbFunctionRead() to obtain data 
            }
        }
    } else {
        // ignore vendor type requests, we don't use any 
    }
    return 0;
}

// -------------------------------------------------------------------------

// 
int blinkmStop(uint8_t addr ) 
{
    if( i2c_start( (addr<<1) | I2C_WRITE ) == 1) {  // start i2c transaction
        i2c_stop();
        return 1;
    }
    i2c_write( 'o' );
    i2c_stop();   // done!
    return 0;
}
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
int main(void)
{
    uchar   i,j;
    
    wdt_enable(WDTO_1S);
    // Even if you don't use the watchdog, turn it off here. On newer devices,
    // the status of the watchdog (on/off, period) is PRESERVED OVER RESET!
    //DBG1(0x00, 0, 0);       // debug output: main starts
    // RESET status: all port bits are inputs without pull-up.
    // That's the way we need D+ and D-. Therefore we don't need any
    // additional hardware initialization. (for USB)
    
    // make pins outputs 
    DDRB |= (1<< PIN_LED_STATUS) | (1<< PIN_I2C_ENABLE); 
    // enable pullups on SDA & SCL
    PORTC |= _BV(PIN_I2C_SDA) | _BV(PIN_I2C_SCL);

    statusLedSet( 0 );      // turn off LED to start

    i2c_init();             // init I2C interface
    i2cEnable(1);           // enable i2c buffer chip

    for( j=0; j<4; j++ ) {
        statusLedToggle();  // then toggle LED
        wdt_reset();
        for( i=0; i<2; i++) { // wait for power to stabilize & blink status
            _delay_ms(10);
        }
    }

    // load params from EEPROM
    eeprom_read_block( &params, &ee_params, sizeof(params_t) );
    blinkmStop( 0 );         // stop all scripts  FIXME:maybe make this a param?
    blinkmSetRGB(0, 0,0,0 ); // turn all off
    if( params.fadespeed != 0 ) {
        blinkmSetFadespeed(0, params.fadespeed);            
    }

#if DEBUG > 0
    uart_init();                // initialize UART hardware
    stdout = stdin = &uart_str; // setup stdio = RS232 port
    puts("linkm debug mode");
#endif

    usbInit();
    usbDeviceDisconnect();  
    for( i=0; i<2; i++ ) {
        statusLedSet( 1 );
        _delay_ms(50);
        statusLedSet( 0 );      // turn off LED to start
        _delay_ms(50);
    }
    // enforce re-enumeration, do this while interrupts are disabled!
    //i = 0;
    //while(--i) {             // fake USB disconnect for > 250 ms 
    //    wdt_reset();
    //    _delay_ms(1);
    //}
    usbDeviceConnect();

#if ENABLE_PLAYTICKER == 1
    // set up periodic timer for state machine
    TCCR1B |= _BV( CS10 );         // 12e6/1/65536 == 183.1  then, / 6 = 30.517
    TIFR1  |= _BV( TOV1 );         // clear interrupt flag
    TIMSK1 |= _BV( TOIE1 );        // enable overflow interrupt
#endif

    sei();
    
    for(;;) {  // main event loop 
        wdt_reset();
        usbPoll();
#if ENABLE_PLAYTICKER == 1
        playTicker();
#endif
        if( goReset ) {
            for( i=0; i<200;i++ ) {  // spin on the USB til watchdog triggers
                usbPoll();
                _delay_ms(10);
            }
        }
    }

    // this is never executed
    resetChip();
    return 0;
}


// ------------------------------------------------------------------------- 

/**
 * Originally from:
 * Name: main.c
 * Project: hid-data, example how to use HID for data transfer
 * Author: Christian Starkjohann
 * Creation Date: 2008-04-11
 * Tabsize: 4
 * Copyright: (c) 2008 by OBJECTIVE DEVELOPMENT Software GmbH
 * License: GNU GPL v2 (see License.txt), GNU GPL v3 or proprietary (CommercialLicense.txt)
 * This Revision: $Id: main.c 692 2008-11-07 15:07:40Z cs $
 */

/*
This example should run on most AVRs with only little changes. No special
hardware resources except INT0 are used. You may have to change usbconfig.h for
different I/O pins for USB. Please note that USB D+ must be the INT0 pin, or
at least be connected to INT0 as well.
*/

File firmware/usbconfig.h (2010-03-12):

/* Name: usbconfig.h
 * Project: V-USB, virtual USB port for Atmel's(r) AVR(r) microcontrollers
 * Author: Christian Starkjohann
 * Creation Date: 2005-04-01
 * Tabsize: 4
 * Copyright: (c) 2005 by OBJECTIVE DEVELOPMENT Software GmbH
 * License: GNU GPL v2 (see License.txt), GNU GPL v3 or proprietary (CommercialLicense.txt)
 * This Revision: $Id: usbconfig-prototype.h 740 2009-04-13 18:23:31Z cs $
 */

#ifndef __usbconfig_h_included__
#define __usbconfig_h_included__

/*
General Description:
This file is an example configuration (with inline documentation) for the USB
driver. It configures V-USB for USB D+ connected to Port D bit 2 (which is
also hardware interrupt 0 on many devices) and USB D- to Port D bit 4. You may
wire the lines to any other port, as long as D+ is also wired to INT0 (or any
other hardware interrupt, as long as it is the highest level interrupt, see
section at the end of this file).
*/

/* ---------------------------- Hardware Config ---------------------------- */

#define USB_CFG_IOPORTNAME      D
/* This is the port where the USB bus is connected. When you configure it to
 * "B", the registers PORTB, PINB and DDRB will be used.
 */
#define USB_CFG_DMINUS_BIT      3
/* This is the bit number in USB_CFG_IOPORT where the USB D- line is connected.
 * This may be any bit in the port.
 */
#define USB_CFG_DPLUS_BIT       2
/* This is the bit number in USB_CFG_IOPORT where the USB D+ line is connected.
 * This may be any bit in the port. Please note that D+ must also be connected
 * to interrupt pin INT0! [You can also use other interrupts, see section
 * "Optional MCU Description" below, or you can connect D- to the interrupt, as
 * it is required if you use the USB_COUNT_SOF feature. If you use D- for the
 * interrupt, the USB interrupt will also be triggered at Start-Of-Frame
 * markers every millisecond.]
 */
#define USB_CFG_CLOCK_KHZ       (F_CPU/1000)
/* Clock rate of the AVR in kHz. Legal values are 12000, 12800, 15000, 16000,
 * 16500 and 20000. The 12.8 MHz and 16.5 MHz versions of the code require no
 * crystal, they tolerate +/- 1% deviation from the nominal frequency. All
 * other rates require a precision of 2000 ppm and thus a crystal!
 * Default if not specified: 12 MHz
 */
#define USB_CFG_CHECK_CRC       0
/* Define this to 1 if you want that the driver checks integrity of incoming
 * data packets (CRC checks). CRC checks cost quite a bit of code size and are
 * currently only available for 18 MHz crystal clock. You must choose
 * USB_CFG_CLOCK_KHZ = 18000 if you enable this option.
 */

/* ----------------------- Optional Hardware Config ------------------------ */

/* #define USB_CFG_PULLUP_IOPORTNAME   D */
/* If you connect the 1.5k pullup resistor from D- to a port pin instead of
 * V+, you can connect and disconnect the device from firmware by calling
 * the macros usbDeviceConnect() and usbDeviceDisconnect() (see usbdrv.h).
 * This constant defines the port on which the pullup resistor is connected.
 */
/* #define USB_CFG_PULLUP_BIT          4 */
/* This constant defines the bit number in USB_CFG_PULLUP_IOPORT (defined
 * above) where the 1.5k pullup resistor is connected. See description
 * above for details.
 */

/* --------------------------- Functional Range ---------------------------- */
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

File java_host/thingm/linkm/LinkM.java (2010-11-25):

/**
 * LinkM -- interface to LinkM USB dongle
 *
 * This is both a library for use by other programs,
 * as well as a command-line demonstration/utilty app
 *
 * Tasks:
 *  - Upload light script    (read text file)
 *  - Download light script  (write text file)
 *  - Send BlinkM command    (as "{'c',0xff,0xff,0xff}" ?)
 *  - Scan I2C bus           (all 127 addrs?)
 *  - Do raw I2C transaction (as linkm-tool)
 *
 * 2009, Tod E. Kurt, ThingM, http://thingm.com/
 *
 */

package thingm.linkm;

import java.io.*;
import java.util.*;
import java.util.regex.*;
import java.awt.Color;

/**
 * The entry point into the LinkM Java API.
 * It depends on a native C library, named (depending on your OS)
 * "libLinkM.dylib", "libLinkM.so", "LinkM.dll". 
 * 
 * This class also provides a main() function that acts as a command-line
 * exerciser of the API.
 *
 */
public class LinkM 
{
  static {
    System.loadLibrary("LinkM");     // Load the library
  }  
  
  static public final int maxScriptLength = 49;

  static public final int writePauseMillis = 15;

  static public int pausemillis = 100;

  static public int debug = 0;

  // Command byte values for linkm_command()
  //
  // !!! NOTE: THIS MUST MATCH enum in linkm-lib.h !!!
  //
  static final int LINKM_CMD_NONE    = 0; // no command, do not use
  // I2C commands
  static final int LINKM_CMD_I2CTRANS= 1; // i2c read/wri (N args: addr+other)
  static final int LINKM_CMD_I2CWRITE= 2; // i2c write    (N args: addr+other)
  static final int LINKM_CMD_I2CREAD = 3; // i2c read     (1 args: addr)
  static final int LINKM_CMD_I2CSCAN = 4; // i2c bus scan (2 args: start,end)
  static final int LINKM_CMD_I2CCONN = 5; // i2c connect/disc (1 args: 1/0)
  static final int LINKM_CMD_I2CINIT = 6; // i2c init         (0 args: )
  // linkm commands
  static final int LINKM_CMD_VERSIONGET= 100;  // version get    (0 args)
  static final int LINKM_CMD_STATLEDSET= 101;  // status LED set (1 args: 1/0)
  static final int LINKM_CMD_STATLEDGET= 102;  // status LED get    (0 args)
  static final int LINKM_CMD_PLAYERSET = 103;  // set params        (7 args)
  static final int LINKM_CMD_PLAYERGET = 104;  // get params        (0 args)
  static final int LINKM_CMD_EESAVE    = 105;  // save params to EE (0 args)
  static final int LINKM_CMD_EELOAD    = 106;  // load params fr EE (0 args)
  static final int LINKM_CMD_GOBOOTLOAD= 107;  // trigger USB bootload

  //---------------------------------------------------------------------------
  // Test Functionality
  //---------------------------------------------------------------------------

  /**
   * Demonstrates library usage by creating little command-line tool
   *
   */
  public static void usage() { 
    println(""+
"Usage: LinkM <cmd> [options]\n" +
"\n"+
"where <cmd> is one of:\n" +
"  --cmd <blinkmcmd> Send a blinkm/i2c command (no spaces in blinkmcmd!) \n" +
"  --off             Turn off blinkm at specified address (or all) \n" +
"  --on              Play startup script at address (or all) \n" +
"  --play <n>        Play light script N \n" +
"  --stop            Stop playing light script \n" +
"  --getversion      Gets BlinkM version \n" +
"  --setaddr <newa>  Set address of blinkm at address 'addr' to 'newa' \n" +
"  --random <n>      Send N random colors to blinkm\n" +
"  --i2cscan         Scan I2c bus for devices  \n" +
"  --i2enable <0|1>  Enable or disable the I2C bus (for connecting devices) \n"+
"  --upload          Upload a light script to blinkm (reqs addr & file) \n"+
"  --download <n>    Download light script n from blinkm (reqs addr & file) \n"+
"  --linkmcmd        Send a raw linkm command  \n"+
"  --linkmversion    Get LinkM version \n"+
"  --statled <0|1>   Turn on or off status LED  \n"+
"  --gobootload      Tell LinkM to go into its bootloaer\n"+
"  --factoryreset    Restore a BlinkM to factory conditions \n"+

"Options:\n"+
"  -h, --help                   Print this help message\n"+
"  -a addr, --addr=i2caddr      I2C address for command (default 0)\n"+
"  -f file, --afile=file        Read or save to this file\n"+
"  -m ms,   --miilis=millis     Set millisecs betwen actions (default 100)\n"+
"  -v, --verbose                verbose debugging msgs\n"+
"\n"+
"Note:  blah blah blah\n"
);
    System.exit(0);
  }
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

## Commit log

2009-07-27 fixed includes for new dir structure
    [main.c]
2009-07-28 added schematics
    [linkmp3.brd, linkmp3.sch]
2009-08-04 added new error code for operating on a non-open linkm. added readinputs command to test why input reading is crashing linkm on non-maxm
    [linkm-lib.c, linkm-lib.h, linkm-tool.c]
2009-08-04 added readinputs command to test why input reading is crashing linkm on non-maxm
    [LinkM.java]
2009-08-08 first checkin of mostly visually-there dual timeline multi-track sequencer based on tm_sequencer_2.0.3.pdf from mikek, based off of my work on a single-timeline multi-track sequencer. removed Relativ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
2009-08-30 ui mostly complete, save/load single track working
2009-08-31 okay gui seems to be working enough to start talking about it. also made good headway on moving all linkm-specific code to main sketchfile, and fixing doBurn() method for multi-blinkm
    [BurnDialog.pde, MultiTrackView.pde, Track.pde]
2009-09-02 removed PlayButton class, didnt need it. added new faked imgs for play/stop button
2009-09-02 finally removed outdated ColorPreview class (previews now done in track views)
2009-09-03 fixed up sendBlinkMColor() logic, clean up color var name defs
    [ButtonPanel.pde, MultiTrackView.pde, Track.pde]
2009-09-04 moved silkscreen font to blinkm-images.jar so it gets exported correctly
2009-09-12 added doDownload, put back in double-click to send color to colorchooser, changed connect semantics in prep for potentially adding arduino support in, started thinking about arduino support use cases
2009-09-12 added i2c timeout ability, debug uart now uses double-speed mode
2009-09-12 fixing up some parseScript and loadScript format. should enclosing curly braces be enforced for single-script files? what about comments on curly brace lines?
    [LinkM.java]
2009-09-30 initial concept of play state machine for stand-alone operation
    [main.c]
2009-12-01 fixed fuses for bootloaded atmega88
2009-12-01 cleaned up pin defines a bit. set bootloaderconfig.h to be correct logic for "ground MOSI to enable bootloader".
    [linkm.c]
2009-12-02 got playticker/playset working, moved to multi-report descriptor (but fixed to report 1)
    [linkm.c]
2009-12-02 moved to new multi-report descriptor (only using report 1 right now), playset working, added better i2cscan
2009-12-02 added getversion & i2cscan & factoryreset
2009-12-03 linkm playticker saves/loads params from eeprom, got timing correct (i think) for playticker
    [linkm.c]
2009-12-07 added i2cScan,getPlayset,setPlayset,eeParamSave,eeParamLoad to LinkM.java
2009-12-07 minor enum and comment fixes
    [linkm-lib.h, linkm-tool.c]
2009-12-08 added updated version
    [linkmp6.brd, linkmp6.sch]
2009-12-12 added linkmp7.sch,brd, which adds pull-down and fixes pull-up issue from linkmp5
    [linkmp7.brd, linkmp7.sch]
2010-01-16 finally. linkm + linkmboot firmware. must use "atmega88" not "atmega88p" when compiling
    [linkmp7.brd, linkmp7.sch]
2010-01-18 cleaned up fuse stuff in Makefile
2010-01-18 cleaned up fuse stuff in Makefile, made it match bootloadHID vals
2010-01-19 hopefully final board, sent to apc for 2 samples
    [linkmp7.brd]
2010-02-13 working-ish preview alpha thing, fixed menus
    [MultiTrackView.pde]
2010-03-03 added broken "send many colors" idea. added hacky debug msgs that I need to remove later. added elapsed time to random for speed tests (4.85 msecs per cmd)
    [LinkM.java]
2010-03-03 fixed multiselect, fixed multi-track to linkm slowdown, improved slightly upload logic, added proper channels top track info
    [BurnDialog.pde, ButtonPanel.pde, MultiTrackView.pde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]
2010-03-14 fixed bootload Makefile to be multi-platform, changed executable name, added msleep() idea (which doesnt seem to really work on windows reliably), and added -R flash-reset-checkForLinkM
    [main.c]
2010-03-14 added chip reset on gobootload, added startup status LED flash, added initial reportId parsing (but fails for reportId=2)
    [linkm.c]
2010-03-17 small fixes, and added menu idea for ROM script trackfill
    [Log.pde, MultiTrackView.pde]
2010-03-22 added factory reset, i2cscan, lots of menu changes
    [ButtonPanel.pde, MultiTrackView.pde]
2010-03-23 perhaps found correct auto-connect logic
    [BlinkMSequencer2.pde]
2010-03-23 wrong place for radial-gradient, but at least in svn now
    [MultiTrackView.pde]
2010-03-30 added heartbeat, made larger hitspot on enable button
2010-04-21 fixed makefile a bit more for linux
    [linkm-tool.c]
2010-04-22 small UI fixes, started down path of loading rom scrpts from jar file
    [BlinkMSequencer2.pde, ButtonPanel.pde, MultiTrackView.pde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]
2010-05-07 added first cut of OSCLinkM
2010-05-09 added TwitterBlinkM first light, receives filterd twitterstream
2010-05-16 fixed report buffer size that made it fail on linux
    [linkm-lib.h]
2010-05-17 fixed up i2c scan tool
    [BlinkMSequencer2.pde, GridTestDialog.pde, MultiTrackView.pde]
2010-05-17 visual fixup for windows
    [BlinkMSequencer2.pde]
2010-05-18 minor fixups for non-mac systems
    [BlinkMSequencer2.pde]
2010-05-19 fixed up file load/save
    [BlinkMScriptTool2.pde]
2010-05-25 figured out libusb-compat on OS X, but open causes weird bus hangs on com_apple_driver_AppleUSBCardReaderUMC, so reverting to libusb-legacy
    [linkm-lib.c, linkm-tool.c]
2010-05-26 minor fixups in java interface
    [LinkM.java]
2010-05-30 found workaround to weird deep cocoa assert failure in macosx from 10.6 update 2. basically, don't call setVisible(true) until you are in draw()
    [BlinkMScriptTool2.pde]
2010-06-05 added thread sleep to workaround macosx assert issue
    [TwitterBlinkM.pde]
2010-08-31 added rudimentary cut-paste and menubar to BlinkMScriptTool2
2010-09-17 blinkmsequencer2: made copy/cut/paste work correctly, fixed selection with keyboard (sorta)
    [BlinkMSequencer2.pde, MultiTrackView.pde, Track.pde]
2010-09-28 blinkmsequencer2: lots of changes. support for arduino+blinkmcommunicator, intra-track copy-paste, fixed color selection on colorchooser
    [BlinkMComm2.pde, BlinkMSequencer2.pde, BurnDialog.pde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]
2010-09-29 blinkmsequencer2: flushed out blinkmcomm functionality more to mirror linkm functionality, added i2c scan for arduino mode, added select all, added setting ROM script playback
2010-09-29 blinkmsequencer2: renamed FixedColorSelection model to .pde
    [BlinkMComm2.pde, BlinkMSequencer2.pde, FixedColorSelectionModel.pde]
2010-09-30 blinkmsequencr2: added gradient feature, added tooltips, added click-track-label-to-change, fixed flickering File menu bug on windows, improved help screen a little
    [BlinkMComm2.pde, BlinkMSequencer2.pde, FixedColorSelectionModel.pde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]
2010-09-30 blinkmsequencr2: added blinkm i2c addr changing, fixed up help screen more
    [BlinkMSequencer2.pde]
2010-11-25 fixed to use newer libusb on macosx
    [LinkM.java]
2011-01-02 BlinkMSequencer2: removed "final static" from version and debug globals of new compiler failings with new Java or Processing (I suspect Processing parsing update dumbness)
    [BlinkMSequencer2.pde]
2011-01-25 BlinkMScriptTool2: added bigger delay for ctrlm, added main window height fix for Windows
    [BlinkMScriptTool2.pde]
2011-06-18 linkm-tool: added flash and readinputs (untested) command, in Makefile added SINGLEARCH compile option for macosx to attempt to compile for only current archiecture instead of x86_64, i386, and ppc
2011-06-18 linkm-tool: fixed minor text output
    [linkm-tool.c]
2014-06-08 fixed 51-linkm.rules for modern Ubuntu
    [linkm.c]
2015-06-19 BlinkMScriptTool2 fixes for modern Processing
    [BlinkMScriptTool2.pde]
2026-04-05 LinkM emulator in Arduino
2026-04-05 LinkM_ProMicro: fix rxBuf overflow corrupting I2C data bytes
    rxBuf was sized to REPORT1_COUNT (8 bytes) but the host sends 17 bytes
    per SET_REPORT: [report_id][16 payload bytes]. After skipping the
    report ID, commands like --color (num_sent=5) needed rxBuf[8], which
    overflowed into txBuf[0] — always 1 (the report ID echo) — injecting
    a stray b=1 into every I2C write and causing faint blue on all colors.
    Fix: add REPORT1_RXSIZE=16, widen rxBuf to match, copy full 16-byte
    payload in setup(). txBuf stays at REPORT1_COUNT=8 (response only).
    [LinkMHID.cpp, linkm_protocol.h]
2026-04-05 LinkM_ProMicro: fix status LED setting
    [LinkMHID.cpp, LinkM_ProMicro.ino]

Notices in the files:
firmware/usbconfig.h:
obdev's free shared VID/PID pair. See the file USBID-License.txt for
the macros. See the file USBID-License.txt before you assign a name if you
